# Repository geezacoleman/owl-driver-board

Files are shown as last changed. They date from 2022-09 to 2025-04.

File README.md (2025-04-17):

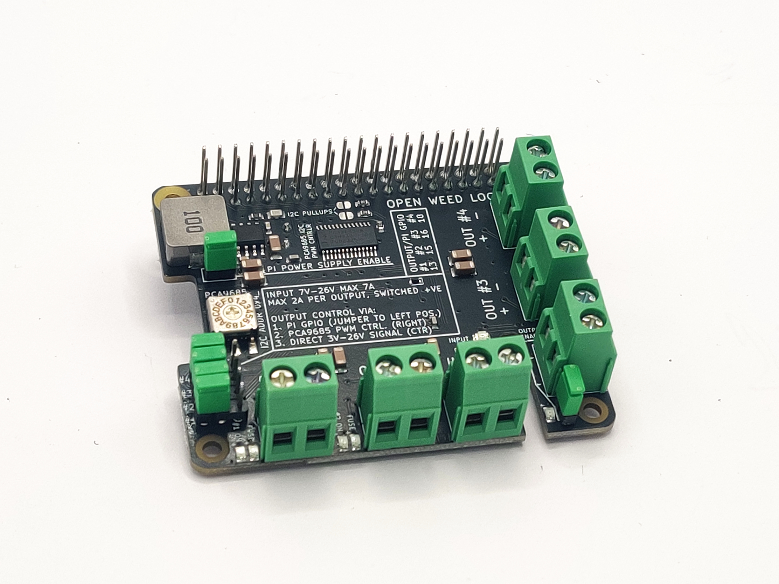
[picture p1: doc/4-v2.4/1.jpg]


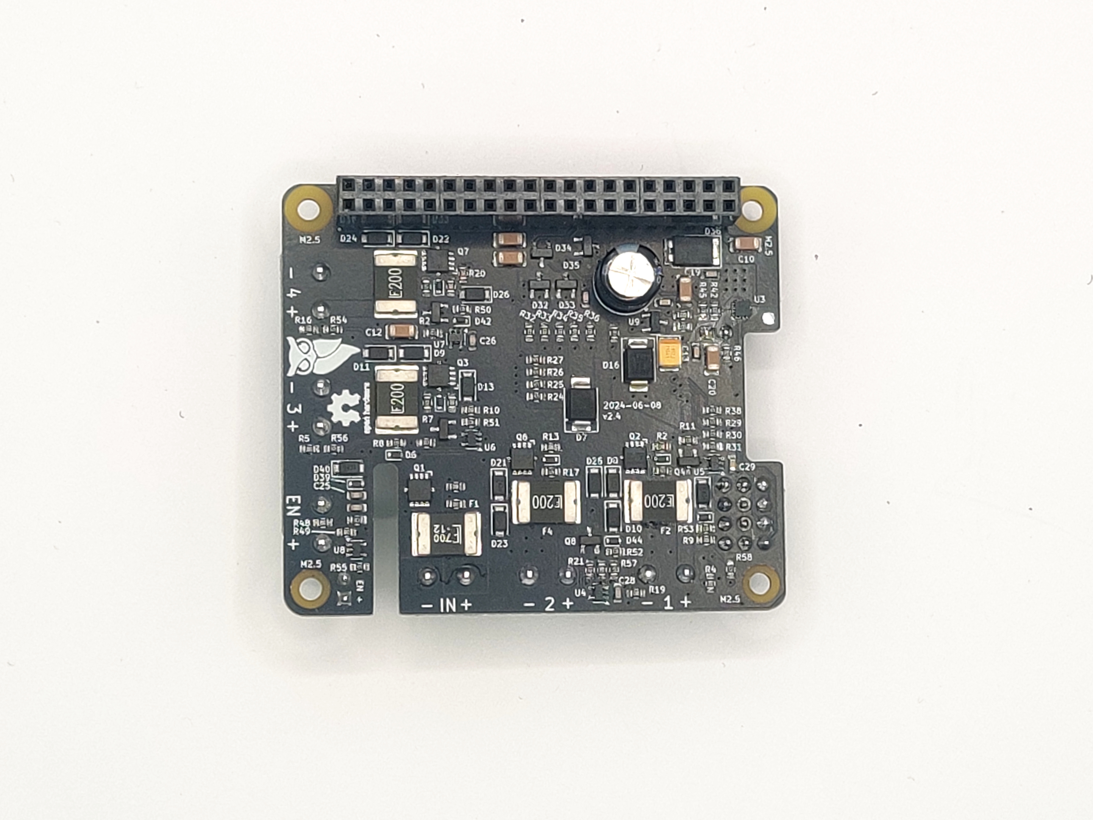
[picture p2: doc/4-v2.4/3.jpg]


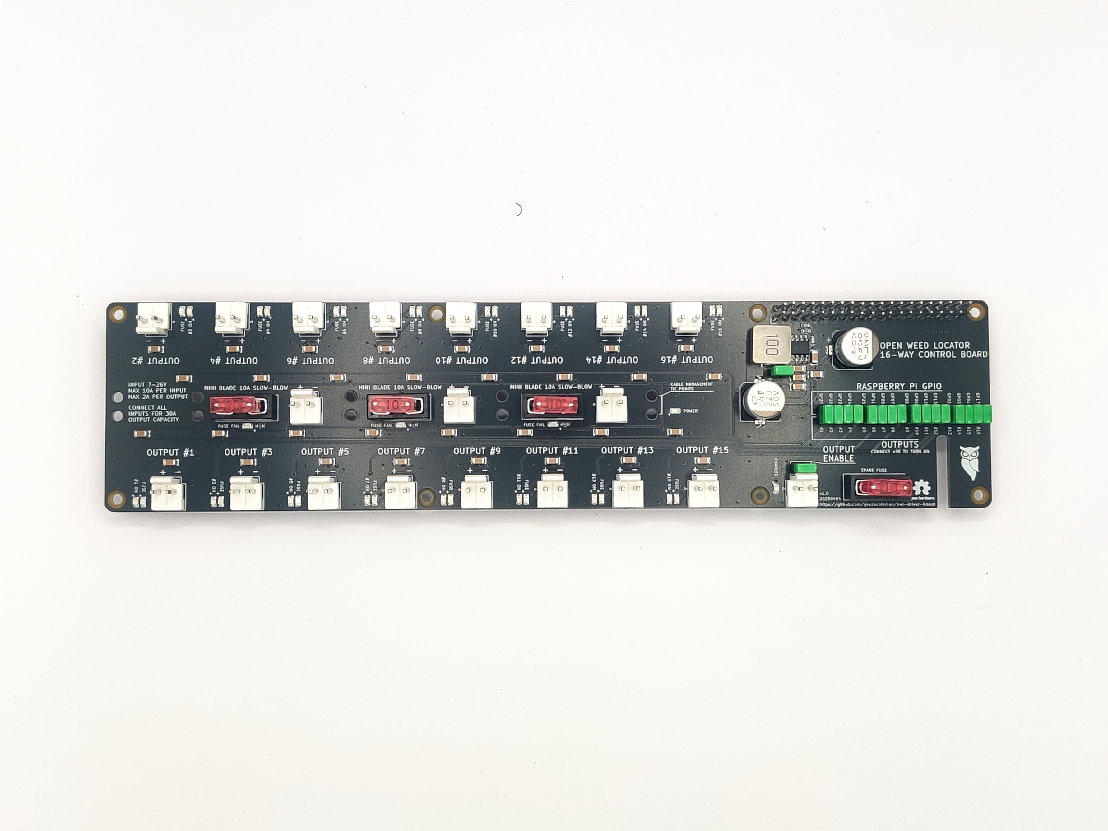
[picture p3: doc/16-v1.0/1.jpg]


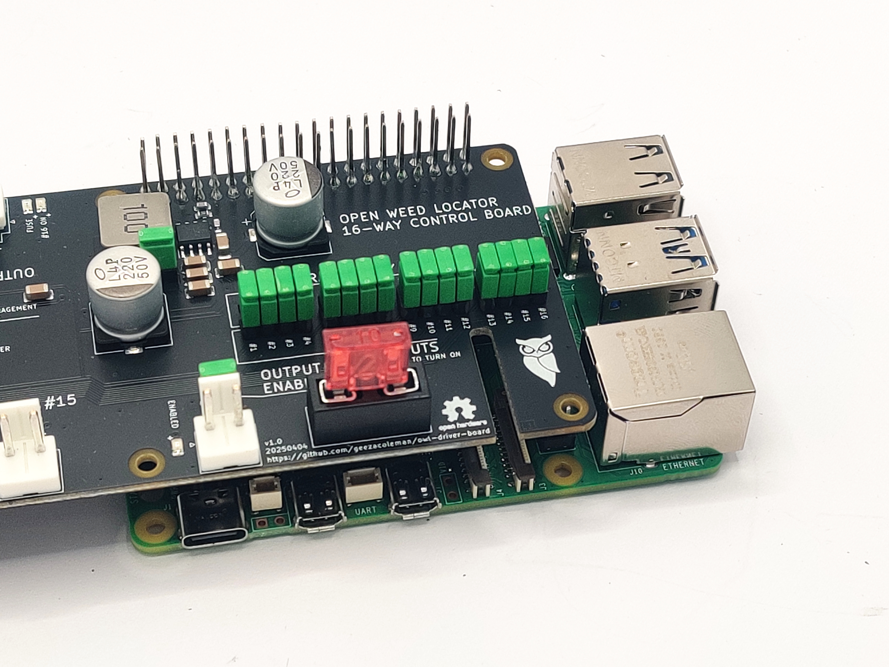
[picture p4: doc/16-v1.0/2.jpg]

 
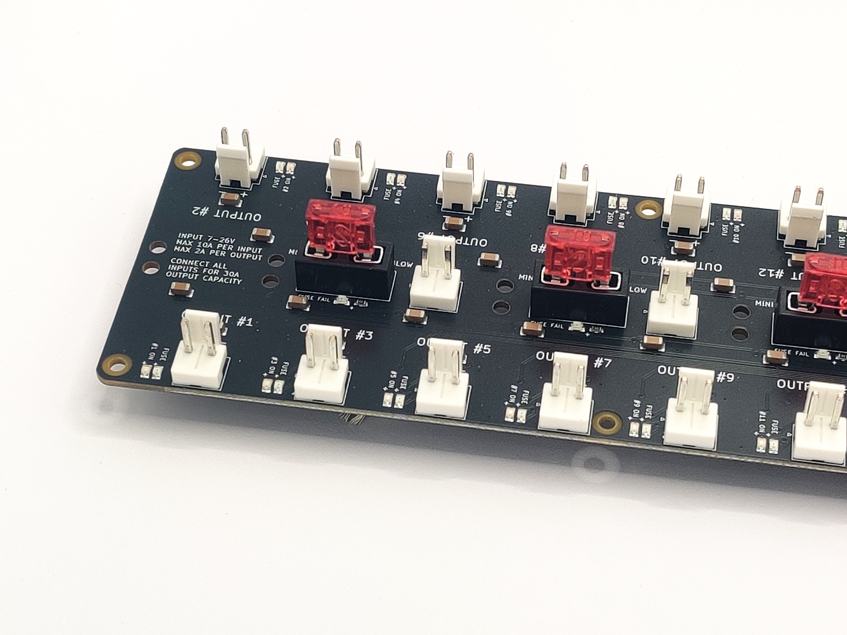
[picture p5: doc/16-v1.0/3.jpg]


The OWL Driver Board is a solid-state relay HAT for the Raspberry Pi. It was
developed for use with the [Open Weed Locator](https://github.com/geezacoleman/OpenWeedLocator) 
but is suitable for any high-power, industrial, automotive or agricultural application.

It allows a Raspberry Pi to drive either 4x or 16x 2A outputs in any 12V or 24V
system, with the solid state switching allowing PWM control, including for
dimming LED strips. Outputs can be placed in parallel for more power if needed.

It is able to tolerate high levels of electrical noise, reverse polarity, short
circuit conditions and over voltage. It also protects the Pi from all this
electrical nastiness and provides a filtered source of 5V @ 5A!

It's ideal for use safely driving LED strips, high power motors, relays and
solenoids from a Raspberry Pi.

The board aims to be difficult to misconfigure and hard to damage.
Self-resetting polyfuses on the input and outputs limit current, and
TVS+Schottky diodes provide reverse polarity protection, protection against
noise and inductive voltage spikes, and over-voltage protection. This
protection also extends to communication buses with the Raspberry Pi.

# Features

### Both models (4x and 16x output versions)

* Open Hardware, made in the UK: schematics and design files freely available.
* Working voltage 7-26V
* 4x or 16x fused outputs, each max. 2A, high-side switched
* 1x e-stop / global enable input
* Outputs can be driven in multiple ways, configurable by a header
* From Raspberry PI GPIOs
* Directly from external control, via wires to a header. Control inputs are tolerant up to 26V.
* Buck converter generates 5.1V @ 3A continuous / 5A burst to power the Raspberry Pi (Pi 5 compatible!)
* Input and outputs are fused, with protection against over-voltage, reverse polarity, and inductive spikes
* LED indication of blown fuses

### Additional features for the 4x output version only

* 1x fused input max. 7A
* Self-resetting input polyfuse
* Integrated PCA9685 PWM driver allows optional PWM control via I2C, compatible with Adafruit PCA9675 Python libraries
* Input and output connectors use high-quality Phoenix Contact screw terminals
* Version 2.4

### Additional features for the 16x output version only

* 3x fused inputs max. 10A each (connect all inputs in parallel for 30A total board input power)
* 10A mini-blade fuses on inputs
* Spare fuse holder
* Inputs and outputs use JST VH connectors
* Version 1.0

# Purchase a finished board

You can buy a finished board (4x or 16x output versions) via the following distributors:

 * [paradar.co.uk](https://paradar.co.uk/products/owl-driver-board-raspberry-pi-automotive-relay-hat)

# Changelog

## 16x v1.1

* Correctly connect the input connectors to the input fuses.

## 16x v1.0

* Initial prototype of a 16-output version of the PCB. Note the Gerbers for
  this version have a bug - the input connectors are not attached to the fuse
  input, and a link must be manually soldered.

## 4x v2.4

* Add an "output enable" terminal (J10) for use with an emergency stop switch.
  Outputs are enabled when the terminal is shorted; they are disabled when it
  is disconnected.

## 4x v2.3

* Improved Pi regulator efficiency (81% -> 87%) to reduce heat generated when
  driving a Raspberry Pi 5

## 4x v2.2

* Change out the switching buck regulator from a 2A max limit to a 5A model.
  Increase the regulation voltage from 5.0V -> 5.1V to drive a Raspberry Pi 5
  without undervoltage warnings.
* Add a LM73100 ideal diode on the Pi 5V output to ensure there is no backflow
  of current from the Pi into the board when powered off, and the Pi has a
  separate USB-C power supply.

## 4x v2.1

* Add a slot for the Raspberry Pi camera connector, to allow the ribbon cable
  to easily pass through the driver board.
* Remove stacking power connector to allow space for the cable slot. If
  stacking is required, board power inputs should be wired in parallel.
* Fix major error in v2.0 where MOSFET rotations were incorrect
* General manufacturability improvements (component polarity in silkscreen)

## 4x v2.0

* Significantly rework layout to allow space for instructions on the top. Move
  most components to the bottom layer.
* Change MOSFETs from TO-220 to a compact SMD footprint.
* Add indicator LED to each output and the power input.
* Switch to generic spring connectors that are PTH rather than SMD; the Wago
  SMD connectors did not hold up well in use.
* Change diodes from SMA to DO-123F to save space.
* Change most resistors from 0805 to 0603 to save space.

## 4x v1.0

Initial prototype.

# Schematic and layout

KiCanvas links:

 * [Schematic](https://kicanvas.org/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)
 * [Layout](https://kicanvas.org/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)

# License

This open hardware project is Copyright (c) 2022 Guy Coleman and Patrick Coleman, and is released under an MIT license.

# Stacking

The HATs may be stacked and controlled with the PCA9685 by selecting different
I2C addresses for each board in the stack. In this configuation, the input power
terminals should be wired in parallel. Ensure that the wires used are rated for
sufficient current.

When stacked and in GPIO mode, turning on output #1 from the Raspberry Pi will
turn on all #1 outputs in the stack.

For individual control of all outputs in the stack
1. Set jumpers on header J6 to control outputs via the PCA9685 (the "PWM" setting).
1. Set SW1 to select a different address for each board in the stack.
1. Use the Adafruit PCA9685 Python library on the Raspberry Pi to communicate
   with each board via the chosen I2C addresses and control outputs
   individually.

Pi pin 22 (GPIO25) is connected to the PCA9685 Output Enable pin. Driving this
pin high on the Pi will disable all outputs in the stack (eg, for a software
emergency stop). It must be driven low for normal operation.

# Manufacturing

The project is set up for easy manufacture and assembly with JLCPCB, though it
will work with other suppliers too. All components should be available at
JLCPCB/LCSC and LCSC part numbers are included in KiKad fields for each part.

If you are having JLCPCB assemble the boards for you, you must manufacture in
panels (two boards per panel), as the board is too small for assembly alone. If
you will be assembling yourself, use pcb/gerbers/gb-owl-driver-board.zip for a single board.

1. Upload pcb/gerbers-panel-v2.4/gb-owl-driver-board-v2.4.zip to [JLCPCB's order tool](https://cart.jlcpcb.com/quote)
1. Configure the PCB manufacture settings to your requirements. Select "Confirm production file: Yes"
1. Select SMT assembly, and configure as follows: "Standard" assembly, "Both sides", and "Confirm production file". Click Confirm.
1. When prompted, upload the BOM (pcb/owl-driver-board_bom_jlc.csv) and Component Placement/CPL (pcb/owl-driver-board_cpl_jlc.csv) files.
1. Complete the SMT assembly wizard, aligning the parts to the board if necessary.

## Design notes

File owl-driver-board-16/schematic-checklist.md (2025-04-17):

# Schematic review checklist

## General

* [x] CAD ERC 100% clean. If some errors are invalid due to toolchain quirks, each exception must be inspected and signed
off as invalid.
* [x] Verify pin numbers of all schematic symbols against datasheet or external interface specification document (if not yet board proven).
* [x] Schematic symbol matches chosen component footprint
* [x] Thermal pads are connected to correct power rail (may not always be ground)
* [-] Debug interfaces are not power gated in sleep mode

## Passive components
* [-] Power/voltage/tolerance ratings specified as required
* [x] Ceramic capacitors appropriately de-rated for C/V curve
* [x] Polarized components specified in schematic if using electrolytic caps etc
* [x] Filters: component footprint is large enough for rated current, and appropriate for RF characteristics
* [x] Different component values minimised/combined where possible
* [x] Parts selected for every schematic symbol
* [x] "Basic" parts selected for passives where possible

## Power supply

### System power input

* [x] Reverse voltage protection at system power inlet
* [x] Fusing at system power inlet
* [-] EMI common mode/low-pass filtering at power inlet (if needed)
* [-] Check total input capacitance and add inrush limiter (if needed)
* [-] Low pass filter included after main buck regulator (if needed)

### Regulators

* [x] Under/overvoltage protection configured correctly if used
* [x] Verify estimated power usage per rail against regulator rating
* [x] Current-sense resistors on power rails after regulator output caps, not in switching loop
* [x] Remote sense used on low voltage or high current rails
* [x] Linear regulators and voltage reference ICs are stable with selected output cap ESR
* [x] Confirm regulator strap pin configuration against datasheet (check for voltage offset)
* [x] Confirm power rail sequencing against device datasheets (if needed)

### Decoupling
* [x] Decoupling present for all ICs
* [x] Decoupling meets/exceeds vendor recommendations if specified
* [x] Bulk decoupling present at buck/boost regulators (input and output)
* [x] RF boards: standard 0402 decoupling cap selected for frequency of interest and used at every IC

### General
* [x] All power inputs fed by correct voltage
* [x] Analog rails filtered/isolated from digital circuitry as needed
* [x] LNAs, input opamps on dedicated power rails

## Signals

### Digital

* [x] Signals are correct logic level for input pin
* [x] Pullups on all open-drain outputs
* [x] TX/RX wired correctly for UART, SPI, MGT, etc
* [x] Enable pins: Active high/low polarity correct
* [x] EXTI and/or timer pins used for UI elements (buttons, rotary encoders)
* [x] STM32: special pin functions confirmed and allocated in Eclipse
* [x] STM32: check software pullups/pulldowns are available on pins that need it (I2C)

### Analog/RF

* [x] DC blocking cap before all amplifiers, and on all inputs/outputs
* [x] Amplifier bias inductors + filter inductors do not short power rail to ground
* [x] Gas discharge protection on all RF inputs/outputs
* [x] RC time constant for attenuators sane given ADC sampling frequency
* [x] Verify frequency response of RF components across entire operating range. Don't assume a "1-100 MHz" amplifier has the
same gain across the whole range.
* [x] Verify polarity of op-amp feedback
* [x] Cages/shields selected for each schematic block

### Clocks

* [x] All oscillators meet required jitter / frequency tolerance. Be extra cautious with MEMS oscillators as these tend to have higher jitter.
* [x] Correct load caps provided for discrete crystals
* [x] Crystals only used if IC has an integrated crystal driver

### Strap/init pins
* [x] Pullup/pulldowns on all signals that need defined state at boot
* [x] Strap pins connected to correct rail for desired state
* [x] JTAG/ICSP connector provided for all programmable devices
* [x] Config/boot flash provided for all FPGAs or MPUs without internal flash

### External interface protection

* [x] Power outputs (USB etc) current limited
* [x] ESD protection on data lines going off board

### Debugging / reworkability

* [x] Use 0-ohm resistors/solder jumpers vs direct hard-wiring for strap pins when possible
* [x] Provide multiple ground clips/points for scope probes
* [x] Multimeter + U.FL test points on all power rails
* [x] Test points on interesting signals which may need probing for bringup/debug
* [x] Dedicated ground in close proximity to test points
* [x] LED on every power rail
* [x] Several spare GPIOs broken out, unless board completely characterised

## Thermal

* [x] Power estimates for all large / high power ICs
* [x] Thermal calculations for all large / high power ICs
* [x] Specify heatsinks as needed

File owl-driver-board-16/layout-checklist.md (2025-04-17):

# Layout review checklist

## General setup

* [x] [Schematic review](schematic-checklist.md) complete and signed off, including pin swaps done during layout
* [x] CAD design rules configured with fab's minimum tolerances, or better
* [x] 2-3 standard via sizes chosen (signal, power) & well within fab tolerances
* [x] 2-5 standard trace sizes chosen (small signal, small power, main power) & well within fab tolerances
* [-] Align one standard trace size to 50ohm coplanar waveguide/stripline width (if used)
* [-] Zone clearance set appropriately for coplanar waveguides
* [-] Appropriate net clearance set for high-voltage nets
* [-] Cage/shield footprints placed before layout starts

## Decoupling

* [x] Decoupling caps as close to power pins as possible
* [x] Low inductance mounting used for decoupling (prefer ViP if available, otherwise "[]8" shaped side vias
* [x] Large planes filled with stitching vias (5mm grid, or 1/20th wavelength whichever smaller)

## DFM / yield enhancement

* [x] Layout DRC 100% clean
* [x] Controlled impedance, design stackup, thickness, plating and any other parameters recorded in text block on Fab layer
* [-] Confirm impedance calculations include soldermask, or mask removed from RF traces
* [-] Stackup verified with manufacturer and specified in fab notes
* [-] If panelizing, add panel location indicators for identifying location-specific reflow issues
* [x] Layer number markers on each layer copper to ensure correct assembly
* [x] Fiducials present (on both sides of board) if targeting automated assembly
* [x] Fiducial pattern asymmetric to detect rotated or flipped boards
* [x] Soldermask/copper clearance on fiducials respected
* [x] Panelization specified if required

## Footprints

* [x] Confirm components are in stock in the selected package
* [x] Confirm components (especially connectors and power regulators) are capable of desired current in the selected package
* [ ] Verify schematic symbol matches the selected package (confirm datasheet pins vs PCB copper wiring)
* [ ] Confirm pinout diagram is from top vs bottom of package
* [ ] 3D models obtained (if available); board reviewed in 3D to check for courtyard/assembly issues
* [ ] Soldermask apertures on all SMT lands and PTH pads
* [ ] Soldermask fingers between all IC pads

## Differential pairs
* [ ] Routed differentially
* [ ] Skew matched
* [ ] Correct clearance to non-coupled nets

## High-speed signals

* [ ] Sufficient clearance to potential aggressors
* [ ] Length matched if required
* [ ] Minimize crossing reference plane splits/slots or changing layers, use caps/stitching vias if unavoidable
* [ ] Confirm fab can do copper to edge of PCB for edge launch connectors
* [ ] Double-check pad width on connectors and add ground plane cutouts if needed to minimize impedance discontinuities
* [ ] Add stitching vias to ground plane in large top layer ground pads (SMA etc) to avoid resonances

## Power
* [ ] Power planes are not broken by closely-spaced fence vias
* [ ] Unbroken ground planes beneath all high-current traces
* [ ] Sufficient width for planes/traces for required current
* [ ] High voltage - minimum clearance sufficient between all points

## RF
* [ ] High-power outputs well separated from LNA inputs
* [ ] LNA inputs clear of all other active components
* [ ] Keepout under LNA section - no traces or active components on other layers
* [ ] Large clearance around magnetic components (eg. circulators)
* [ ] RF traces smooth/rounded
* [ ] Differential RF pairs have 100ohm impedance, not 50

## Sensitive analog
* [ ] All sensitive components under cages/shields
* [ ] Physically separated from high current SMPS or other noise sources
* [ ] Consider microphone effect on MLCCs if near strong sound sources
* [ ] Power ground return does not cross under sensitive sections

## Mechanical
* [ ] Confirm all connectors to other systems comply with the appropriate mechanical standard (connector orientation, key position, etc)
* [ ] LEDs, buttons, and other UI elements on outward-facing side of board
* [ ] Keep-outs around PCB perimeter, card guides, panelization mouse-bites, etc respected
* [ ] Stress-sensitive components (MLCC) sufficiently clear from V-score or mouse bite locations, and oriented to reduce
bending stress
* [ ] Clearance around large ICs for heatsinks/fans if required
* [ ] Clearance around pluggable connectors for mating cable/connector
* [ ] Clearance around mounting holes for screws
* [ ] Plane keepouts and clearance provided for shielded connectors, magnetics, etc
* [ ] Confirm PCB dimensions and mounting hole size/placement against enclosure or card rack design
* [ ] Verify mounting hole connection/isolation
* [ ] Components not physically overlapping/colliding
* [ ] Clearance provided around solder-in test points for probe tips

## Thermal

* [ ] Thermal reliefs used for plane connections (unless via is used for heatsinking)
* [ ] Solid connections used to planes if heatsinking
* [ ] Ensure thermal balance on SMT chip components to minimize risk of tombstoning

## Solder paste

* [ ] No uncapped vias in pads (except low-power QFNs where some voiding is acceptable)
* [ ] QFN paste prints segmented
* [ ] Small pads 100% size, larger pads reduced to avoid excessive solder volume
* [ ] No paste apertures on card edge connectors or test points

## Solder mask

* [ ] Adequate clearance around pads (typ. 50 um)
* [ ] Fingers between pads on small-pitch components

## Silkscreen

* [ ] Text size within fab limits & consistent across board
* [ ] Text not overlapping drills or component pads
* [ ] Text orientation consistent (within reason)
* [ ] Text removed entirely in, or moved outside of, high component/via density areas
* [ ] Unnecessary silkscreen removed for clarity
* [ ] Power connector polarity marked and verified
* [ ] LED colour marked (if hand assembly)
* [ ] LED/switch/connector purpose marked
* [ ] Spare GPIO headers marked with port name
* [ ] Design/assembly notes included where space permits (antenna dimensions/centre frequency, wiring notes, baud speed, assembly instructions/screw size)
* [ ] High voltage/heat/ESD safety warnings included (if appropriate)
* [ ] Link to project github included (open hardware designs)
* [ ] Traceability markings (revision, date, name, etc) provided and updated
* [ ] Silkscreen box provided for writing/sticking serial number
* [ ] Text mirrored properly on bottom layer
* [ ] Test points labeled if space permits

## Flex specific
* [ ] Components oriented to reduce bending forces
* [ ] Teardrops on all wire-to-pad connections

## CAM production
* [ ] Check impedance-matched width against final fab stackup
* [ ] KiCAD specific: rerun DRC and zone fills before exporting CAM files to ensure proper results
* [ ] Export gerber/drill files at the same time to ensure consistency
* [ ] Visually verify final CAM files to ensure no obvious misalignments

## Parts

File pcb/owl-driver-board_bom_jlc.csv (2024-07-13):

Comment | Designator | Footprint | LCSC Part #
10uF | C1,C2,C3,C4,C5,C10,C11,C12,C14,C15,C16,C18,C19,C20 | C_1206_3216Metric_nosilk | C89835
0.1uF | C6,C7,C9,C17,C21,C25,C26,C27,C28,C29,C30 | C_0603_1608Metric_nosilk | C14663
220uF 25V | C8 | CP_Radial_D8.0mm_P3.50mm | C216322
100uF 6.3V | C13 | CP_EIA-3528-21_Kemet-B | C16133
10p | C22 | C_0805_2012Metric | C107107
2n | C23 | C_0603_1608Metric_nosilk | C1870141
10n | C24 | C_0603_1608Metric_nosilk | C77053
SZYY0805R | D1,D4,D5,D19,D20 | LED_0805_2012Metric | C434431
BZT52C5V1T | D2,D3,D6,D17,D18,D39,D42,D43,D44,D45 | D_SOD-523_silkpolarity | C2987034
SMBJ26A | D7 | D_SMB_silkpolarity | C315992
DSK34 | D8,D9,D10,D11,D12,D13,D21,D22,D23,D24,D25,D26,D40 | D_SOD-123F_silkpolarity | C727076
SMBJ5.0A | D16 | D_SMB_silkpolarity | C83333
SZYY0805YG | D29,D30,D31,D37,D38,D41 | LED_0805_2012Metric | C434435
AZ23C3V3 | D32,D33,D34,D35 | SOT-23_nosilk | C968007
PDS1040L-13 | D36 | D_PowerDI-5 | C154714
2920L700/12 | F1 | Fuse_2920_7451Metric_nosilk | C207092
2920L200DR | F2,F3,F4,F5 | Fuse_2920_7451Metric_nosilk | C207087
CONN_04 | J1 | 1X04_NO_SILK | C358686
RASPBERRYPI-40-PIN-GPIO | J2 | Pin_Header_Straight_2x20 | C35165
1890963 | J3,J4,J5,J7,J8,J10 | Connector_Phoenix-Contact_MKDSN_1890963_P5.0_2x | C3817236
CONN_04X2 | J6 | 2X4 | C358693
PI 5V | J9 | PinHeader_1x02_P2.54mm_Vertical_nosilk | C358684
ENABLE | J11 | PinHeader_1x02_P2.54mm_Vertical_nosilk | C358684
10uH | L1 | L_10.4x10.4_H4.8 | C7461391
AGM60P85AP | Q1,Q2,Q3,Q6,Q7 | PDFN-8-3.3x3.3 | C17701049
2N7002 | Q4,Q5,Q8,Q9 | SOT-23_nosilk | C8545
1k | R1,R2,R3,R4,R5,R9,R10,R13,R14,R15,R16,R19,R20,R23,R39,R40,R48,R49 | R_0603_1608Metric | C21190
470 | R6,R7,R17,R18,R24,R25,R26,R27,R29,R30,R31,R38,R54,R55,R56,R57,R58 | R_0603_1608Metric | C25241
10k | R8,R11,R12,R21,R22,R28,R32,R33,R34,R35,R36,R37,R47,R50,R51,R52,R53 | R_0603_1608Metric | C15401
165k | R41 | R_0603_1608Metric | C22816
10.2k | R42 | R_0603_1608Metric | C22772
43k | R43 | R_0603_1608Metric | C23172
14k | R44 | R_0603_1608Metric | C22803
1.87k | R45 | R_0603_1608Metric | C22850
360k | R46 | R_0603_1608Metric | C23146
SW_Coded_SH-7050 | SW1 | Diptronics-Rotary-Switch-R7M3-16RA-V | C501563
TPS54531DDA | U1 | Texas_R-PDSO-G8_EP2.95x4.9mm_Mask2.4x3.1mm_ThermalVias | C50605
PCA9685PW | U2 | TSSOP-28_4.4x9.7mm_P0.65mm | C2678753
LM73100 | U3 | LM73100-QFN10 | C3210761
74LVC1G08 | U4,U5,U6,U7,U8 | SOT-353_SC-70-5 | C12512
XC6206P332MR | U9 | SOT-23 | C5148692

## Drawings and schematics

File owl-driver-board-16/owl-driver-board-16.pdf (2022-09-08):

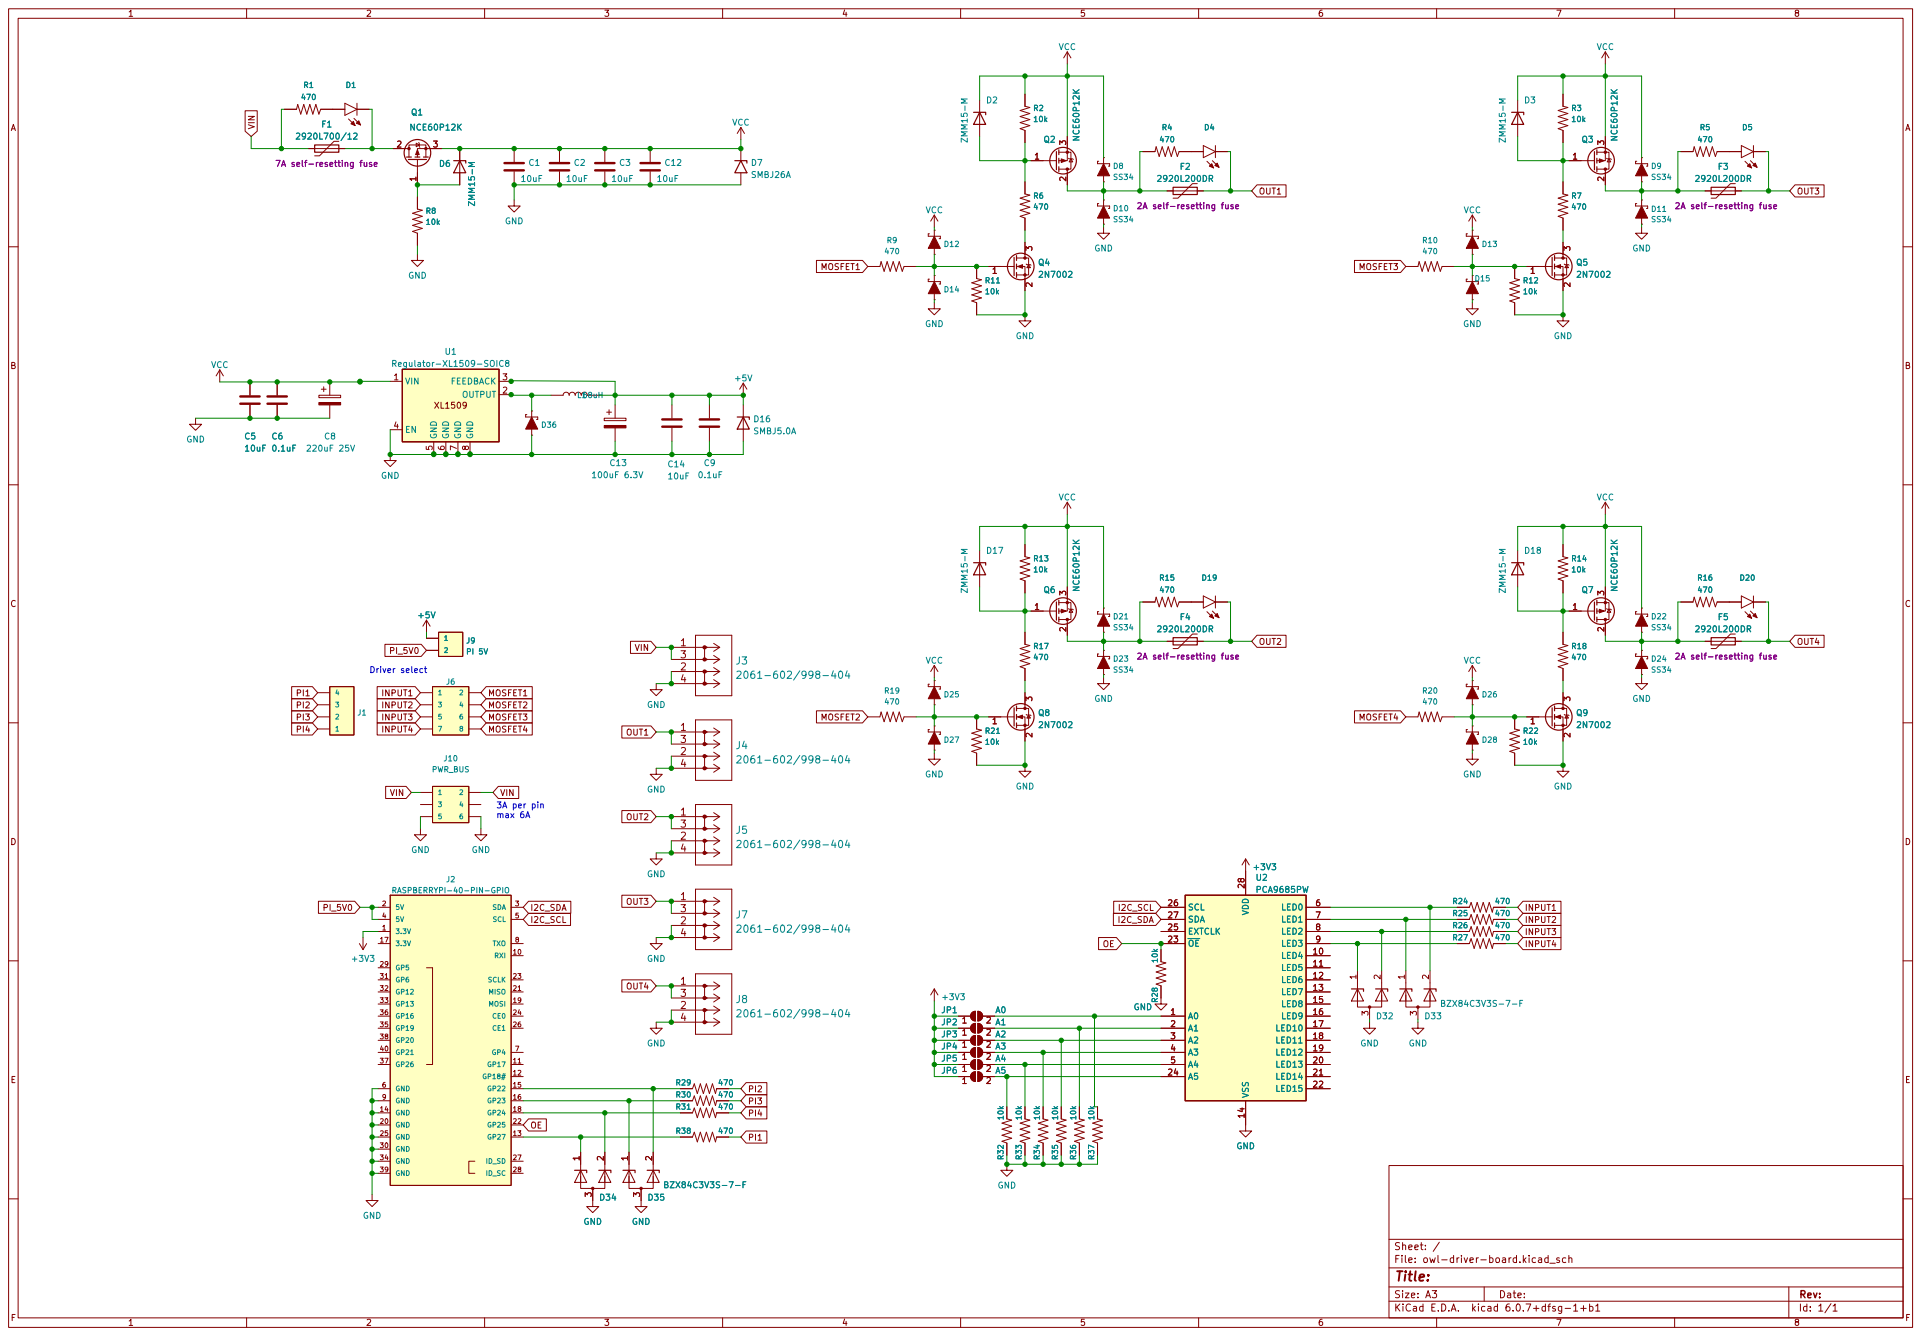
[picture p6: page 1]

JP2 1 1 JP2 | 2 2 A1 A1
JP3 JP3 1 1 | 2 2 A2 A2
JP4 JP4 1 1 | 2 2 A3 A3
JP5 1 1 JP5 | 2 A4
JP6 1 1 | 2 2 A5

File: owl-driver-board.kicad_sch Sheet: /

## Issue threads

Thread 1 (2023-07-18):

I made one!

Minorplanets76, 2023-07-18:
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
I built one by hand (dumb idea), but it seems to be working OK except for the LED's, i.e. the Pi has been running fine for extended periods, and the outputs can be switched on and off.  I don't think my leds are wrong, but I'm veryu much an amatuer.

An issue I see is that the camera cable is hard up against the bottom of the board and it running over fuses and power and stuff so might not be reliable long term in a dusty,vibrating environment. It might be better to have a penetration in the board.

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
There's a similar issue where one of the outputs is a bit hidden behind the USB3 ports.  Probably not an issue unless using ferrules.

Anyway, I'll continue to test.  I'm considering doing a less featured board with smd components on one side only...might be a little cheaper and easier.

Thanks for the design!

geezacoleman, 2023-07-19:
This is very exciting to see! How did you solder/assemble it?

Thanks for the feedback too - having a slot for the cable is probably a good idea. I was wondering why it wasn't so compact on ours, but I think in the manufactured one it used longer standoffs for the GPIO, which provided more room between the Pi and the base of the top board. This also meant the USB port wasn't blocking the outputs. Still, the cable does sit up against the base of the board - perhaps at least some rubber tape could increase longevity.

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

Which features would you retain/remove? We could do a couple of versions depending on what people are after.

Minorplanets76, 2023-07-20:
I hand soldered it, which probably wasn't a good idea.  JLPCB didn't have the wago connectors and I didn't really want 10, plus 2 sided assembly seemed fairly pricey so I figured why not.  It wasn't too bad, but I'm not sure if I'm doing the fuses right.Takes a long time so more out of interest than anything. Tape is a good idea, I'll do that.

I've spent a couple of hours on another version to try and get smd parts on one side.  Haven't managed to get it to fit yet.  I took out the PWM chip and various connectors so that it is just the power supply for the Pi and the Mosfet outputs.  Basically copied the schematic, and took out stuff that didn't seem essential.  I'm assuming PWM could be done in software, but have no idea if that would be true with the OWL overhead.  Using the same part numbers.  Probaby going have to have wires solder to the board.
[Schematic_Owl Driver Board_2023-07-21.pdf](https://github.com/geezacoleman/owl-driver-board/files/12114677/Schematic_Owl.Driver.Board_2023-07-21.pdf)
The only extra I have pondered is to hook up the POE pins assuming battery volatge used on a dumb POE injector.  Might be useful if you go wired network vs wireless.

blinken, 2024-04-08:
Hey @Minorplanets76 , just to let you know we've completed some small revisions (including adding a camera slot!). We've also switched to decent screw terminals rather than the wago connectors as they were a bit of a pain to use.

This is available as [release v2.1 ](https://github.com/geezacoleman/owl-driver-board/releases/tag/v2.1) and we'll be doing a small production run of 10x.

I'm going to go ahead and close this issue, but I really appreciate the feedback. If you still need a board, shoot me a message!

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

Minorplanets76, 2024-04-09:
Good stuff!

On Mon, Apr 8, 2024 at 9:10 PM Patrick Coleman ***@***.***>
wrote:

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

Closed 2024-04-08.

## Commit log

2022-09-03 Initial PCB
    Board is electrically complete, but needs silkscreen adjustments and
    final DRC against fab rules.
    [owl-driver-board.kicad_pcb, owl-driver-board.kicad_sch]
2022-09-07 final board - linear regulator
    Board design finalised with linear regulator - max 12V operation.
    [owl-driver-board-B_Cu.gbr, owl-driver-board-B_Mask.gbr, owl-driver-board-B_Paste.gbr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]
2022-09-08 board, add v1.0 single-board design
    Includes buck converter for 26V operation. Component positions and
    rotations validated against design/JLCPCB assembly preview.
    [owl-driver-board-B_Cu.gbl, owl-driver-board-B_Mask.gbs, owl-driver-board-B_Paste.gbp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]
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2022-09-08 change BZX84C3V3S-7-F diode pair for AZ23C3V3
    JLCPCB part C306656 -> C968007
    As out of stock (equivilent part)
    [owl-driver-board.kicad_sch, owl-driver-board_bom_jlc.csv]
2022-09-09 J3,4,5,7,8 - substitute connector part
    We previously specified WAGO spring-claml connector 2060-452/998-404 (7A), but
    the footprint used was the WAGO 2061-602/998-404 (17A). Substitute the
    part in the BOM; possibly the smaller model could be used to make the
    board less crowded in a future optimisation.
    Old LCSC Part: C2765055
    New LCSC Part: C2765058
    [owl-driver-board.kicad_sch]
2022-09-09 clean up old CPL/BOM and include command to generate
    This uses jlc-kicad-tools (https://github.com/matthewlai/JLCKicadTools)
    [owl-driver-board-bom.xlsx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]
2022-09-09 correct part number for J8,J3,J4,J5,J7 WAGO connectors
    [owl-driver-board.kicad_pcb, owl-driver-board_bom_jlc.csv, panel.kicad_pcb]
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2024-03-09 driver board, v2.0 revisions
    - Add indicator LED to each output and the power input
    - Switch to generic spring connectors that are PTH rather than SMD,
    the wago SMD ones weren't super robust
    - Move most of the components to the bottom of the board, so that the
    top can be an unbroken ground plan + space for silkscreen instructions
    - Change diodes from SMA to DO-123F
    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
    [owl-driver-board.kicad_pcb, owl-driver-board.kicad_sch]
2024-03-16 v2.0 passed verification, ready to panelise
    [owl-driver-board.kicad_pcb, owl-driver-board.kicad_sch]
2024-03-16 v2.0, add gerbers and CPL (not yet production verified)
    [owl-driver-board_bom_jlc.csv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]
2024-03-16 v2.0, ensure all components are in the CPL file, fix some incorrect component properties
    [owl-driver-board.kicad_pcb, owl-driver-board.kicad_sch, owl-driver-board_bom_jlc.csv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]
2024-03-16 v2.0, fix CPL rotations
    [cpl_rotations_db.csv, owl-driver-board_cpl_jlc.csv]
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2024-03-17 v2.0, adjust LED spacing to avoid collision with the spring terminals
    [owl-driver-board.kicad_pcb, owl-driver-board.kicad_sch, owl-driver-board_bom_jlc.csv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]
2024-03-17 v2.0, remove final handsoldering SMB footprint, add JLC order number placeholder, small silkscreen fixes
    [owl-driver-board.kicad_pcb, owl-driver-board.kicad_sch, owl-driver-board_bom_jlc.csv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]
2024-03-19 v2.0 as manufactured
    Final revisions to improve manufacturability -
    * Adjust component rotatations to suit JLCPCB (there are still some
    issues here unfortunately - I think perhaps a bug in their PCBA
    software just based on the rotation of the connectors)
    * Tweak LED position and mounting hole size to avoid collision with the
    spring clamp connectors.
    [owl-driver-board.kicad_pcb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]
2024-03-19 silkscreen, add polarity for tantalum cap & fix CPL rotation
    [owl-driver-board.kicad_pcb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]
2024-04-07 correct incorrect orientation of main switching MOSFETs. Add reverse/backfeed protection MOSFET at PI 5V supply
    [owl-driver-board.kicad_pcb, owl-driver-board.kicad_sch]
2024-04-07 stacking, remove stacking connector
    Remove the stacking connector to give us more space to expand the
    display ribbon cable slot. On the Pi5, there can be up to two ribbon
    cables which are located slightly closer to the corner of the board. The
    previous configuration was hard to wire.
    Extend the ribbon cable slot to the edge of the board.
    The board can still be stacked - control signals will still pass through
    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
    [owl-driver-board.kicad_pcb, owl-driver-board.kicad_sch]
2024-04-07 clean up mosfet rotations, connections and clearance after fixing schematic
    [owl-driver-board.kicad_pcb, owl-driver-board.kicad_sch]
2024-04-07 small silkscreen adjustments, add polarity markings for diodes and capacitors to aid assembly
    [owl-driver-board.kicad_pcb, owl-driver-board.kicad_sch]
2024-04-08 v2.1, final verification
    Small silkscreen adjustments
    Change MOSFET pullup resistor from 10k to 1k (estimated max switching
    frequency 70kHz -> 700kHz)
    Add revision information
    [owl-driver-board.kicad_pcb, owl-driver-board.kicad_sch]
2024-04-08 remove rounded edges on slot to allow v-cut panelisation, panelise v2.1
    [owl-driver-board.kicad_pcb]
2024-04-08 add pi5 3d model to verify component placement clears the pi bits
    [owl-driver-board.kicad_pcb]
2024-04-08 re-add rounded corners on the slot and adjust panel tab width to avoid errors
    [owl-driver-board.kicad_pcb]
2024-04-08 add silkscreen alignment marker for MOSFETs
    [owl-driver-board.kicad_pcb]
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2024-04-10 v2.1, reduce panel tab width
    Reduce the tab width to ensure it doesn't collide with the new slot
    location & cause confusion during manufacture.
    [owl-driver-board.kicad_pcb]
2024-04-28 add schematic design for 5A regulator, increase output voltage for pi to 5.2V
    [owl-driver-board.kicad_pcb, owl-driver-board.kicad_sch]
2024-04-28 v2.2 final checks
    Final checks for version 2.2, which increases the current limit for the
    Pi regulator to 5A.
    Replace the MOSFET on the Pi power output with a LM73100 ideal diode, as
    this actually provides genuine reverse current protection and prevents a
    USB-C supply on the Pi feeding the high-current sinks on this board.
    [owl-driver-board.kicad_pcb, owl-driver-board.kicad_sch]
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2024-04-29 v2.2, final revisions after fab review
    Add silkscreen orientation markings for SW1 & Q3, and make them clearer for D13.
    Make tabs between boards on the panel slightly shorter to avoid slot
    routing weirdness.
    Update the board characteristics table for v2.2.
    [owl-driver-board.kicad_pcb, owl-driver-board.kicad_sch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]
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2024-05-28 change flyback diode to improve efficiency
    Regulator temperature under 2.5A load is >120°C. replace the flyback
    diode (Vf 850mV -> 450mV) to take efficiency from 80% to 87% per TI's
    calculator.
    Upgrade layout to KiCad v8.0
    [owl-driver-board.kicad_pcb, owl-driver-board.kicad_sch]
2024-05-28 schematic, remove redundant fields
    Fix error on R46 (value 165k -> 360k)
    [owl-driver-board.kicad_sch]
2024-06-03 v2.3, minor placement and silkscreen adjustments
    Run DRC and adjust new components and board constraints to fit. Some new
    tests and constraint paramters were introduced in KiCad 8.0.
    [owl-driver-board.kicad_pcb]
2024-06-08 v2.3, panelize, ready for production
    However we need to make some small changes prior (add a global disable
    input), which will be released as v2.4.
    [owl-driver-board_bom_jlc.csv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]
2024-06-08 v2.4, add estop/global disable
    Add an input to allow all outputs to be controlled remotely. Inputs to
    MOSFETs are adapted to incorporate an AND gate, which has the nice
    advantage of buffering the output so the LEDs will be brighter.
    Clamp inputs to the AND gates to 5.1V with a Zener to prevent damage.
    ERC and DRC passing.
    [owl-driver-board.kicad_pcb, owl-driver-board.kicad_sch]
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2024-06-08 readme, update instructions for v2.4
    Add a changelog to note the major changes in each version.
    Refresh the single-board gerber files.
    [owl-driver-board-B_Cu.gbl, owl-driver-board-B_Cu.gbr, owl-driver-board-B_Mask.gbr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]
2024-06-08 v2.3, add missing gerbers
    These were left out of the original commit
    [panel-B_Cu.gbr, panel-B_Mask.gbr, panel-B_Paste.gbr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]
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2024-06-20 add notes re en connector polarity to schematic
    [owl-driver-board.kicad_sch]
2024-06-20 change 25V 47uF bulk decoupling to 50V 10uF
    47uF capacitor was expensive and close to its limit @ a 24V input, so
    the 10uF capacitor will likely have the same effective capacitance, and
    is considerably cheaper.
    [owl-driver-board.kicad_sch, owl-driver-board_bom_jlc.csv]
2024-07-08 post-manufacturing tweaks
    Reduce spring clamp hole size 1.3 -> 1.2 mm for neater alignment
    Change output enable LED from red to green
    [owl-driver-board.kicad_pcb, owl-driver-board.kicad_sch]
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2024-07-13 bom, fix 10uF capacitor error
    For some reason all the 10uF caps were replaced with 0603 100nF
    versions. Swap for the correct size and value in a generic capacitor.
    [owl-driver-board.kicad_sch, owl-driver-board_bom_jlc.csv]
2025-04-04 add 16-way version of the OWL driver board
    [input.kicad_sch, output_chain.kicad_sch, owl-driver-board-16.kicad_sch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]
2025-04-17 add a 16-way version
    Add a 16-way version of the HAT. Drop the PWM controller to focus on
    GPIO control of 16 outputs, with output enable/e-stop, and keeping the
    25W Pi power supply.
    This version (v1.0) has a small bug in the panel, fixed in v1.1.
    [input.kicad_sch, output_chain.kicad_sch, owl-driver-board-16.kicad_sch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]
2025-04-17 16-way board, fix zone fill issue
    v1.0 of these boards have a bug - the zone priority for the fills
    between the power input connectors and the fuses has the same priority
    as the surrounding zone, so it's random luck whether they are connected
    or not.
    Change the surrounding VCC zone to priority 1 and re-export Gerbers.
    [panel-16-B_Cu.gbr, panel-16-B_Mask.gbr, panel-16-B_Paste.gbr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]
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
